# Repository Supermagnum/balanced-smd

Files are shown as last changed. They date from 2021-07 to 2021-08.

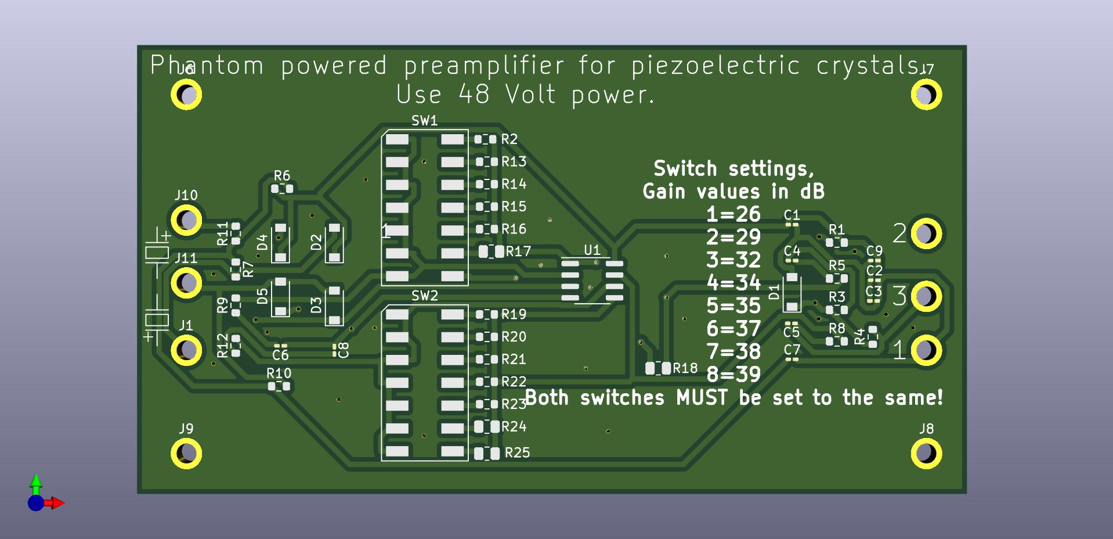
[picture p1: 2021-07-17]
front.jpg

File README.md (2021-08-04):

# balanced-smd
A small PCB that uses two LT6234CS8#TRPBF  op amps to amplify a signal from a contact microphone.

It has balanced output,input and should run on +48 phantom power. Shielded cable must with 3 leads be used for connection to the piezo crystals. Please use 0,5 W metal film resistors with 1% tolerance or better and audio quality capacitors.
C0G (NP0) or X7R capacitors is very good.

It is important that the circuit board is mounted inside a metal box, and Ø2mm conducting metal standoffs are used. The corner pads of the PCB board is reserved for that. Of course the PCB board and components must not come in contact with any metal surface expect the standoffs.

The circuit may benefit from a Zobel network, that is a 680 pF capacitor and a 150 ohms resistor in series between pin 2 and 3 on the output or the input connector. It should avoid high frequency oscillation in the cable.

Schematic diagram:
https://github.com/Supermagnum/balanced-smd/blob/main/smd-balanced.pdf

Component side picture with switch settings versus gain in dB:
https://github.com/Supermagnum/balanced-smd/blob/main/front.jpg

Back side:
https://github.com/Supermagnum/balanced-smd/blob/main/back.jpg

Aisler link:
https://aisler.net/p/YIWINLSK
Aisler can suply this assembled with the SMD components in place.

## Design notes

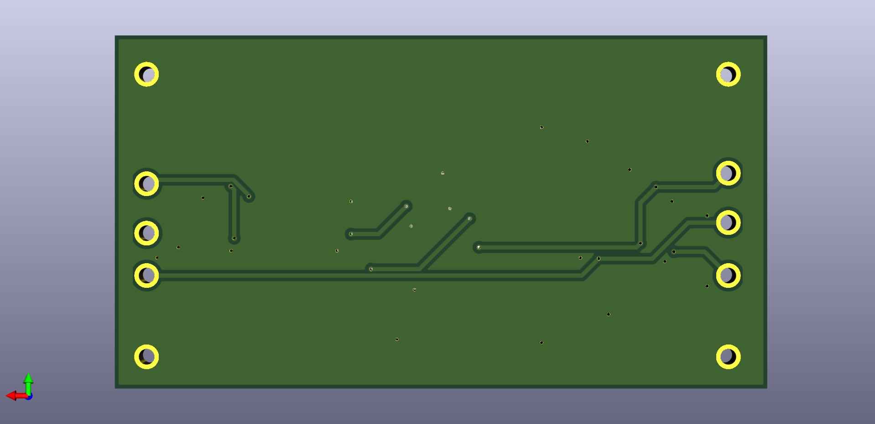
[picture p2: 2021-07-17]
back.jpg

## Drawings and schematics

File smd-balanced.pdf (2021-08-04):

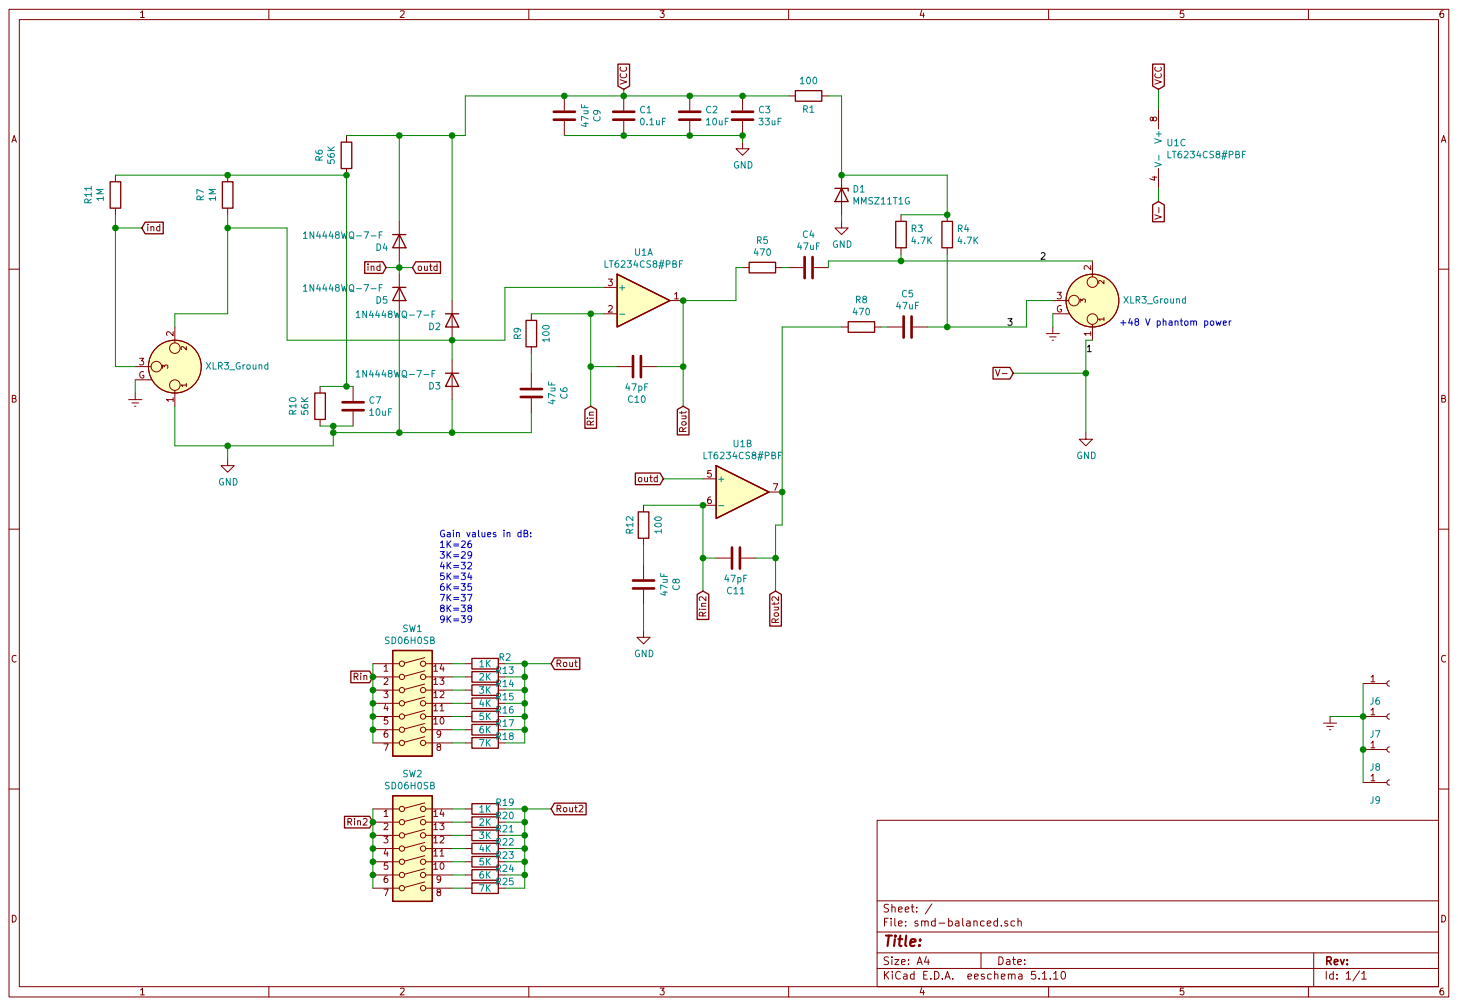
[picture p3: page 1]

Id: 1/1 Title: File: smd-balanced.sch Sheet: / C9 47uF D4

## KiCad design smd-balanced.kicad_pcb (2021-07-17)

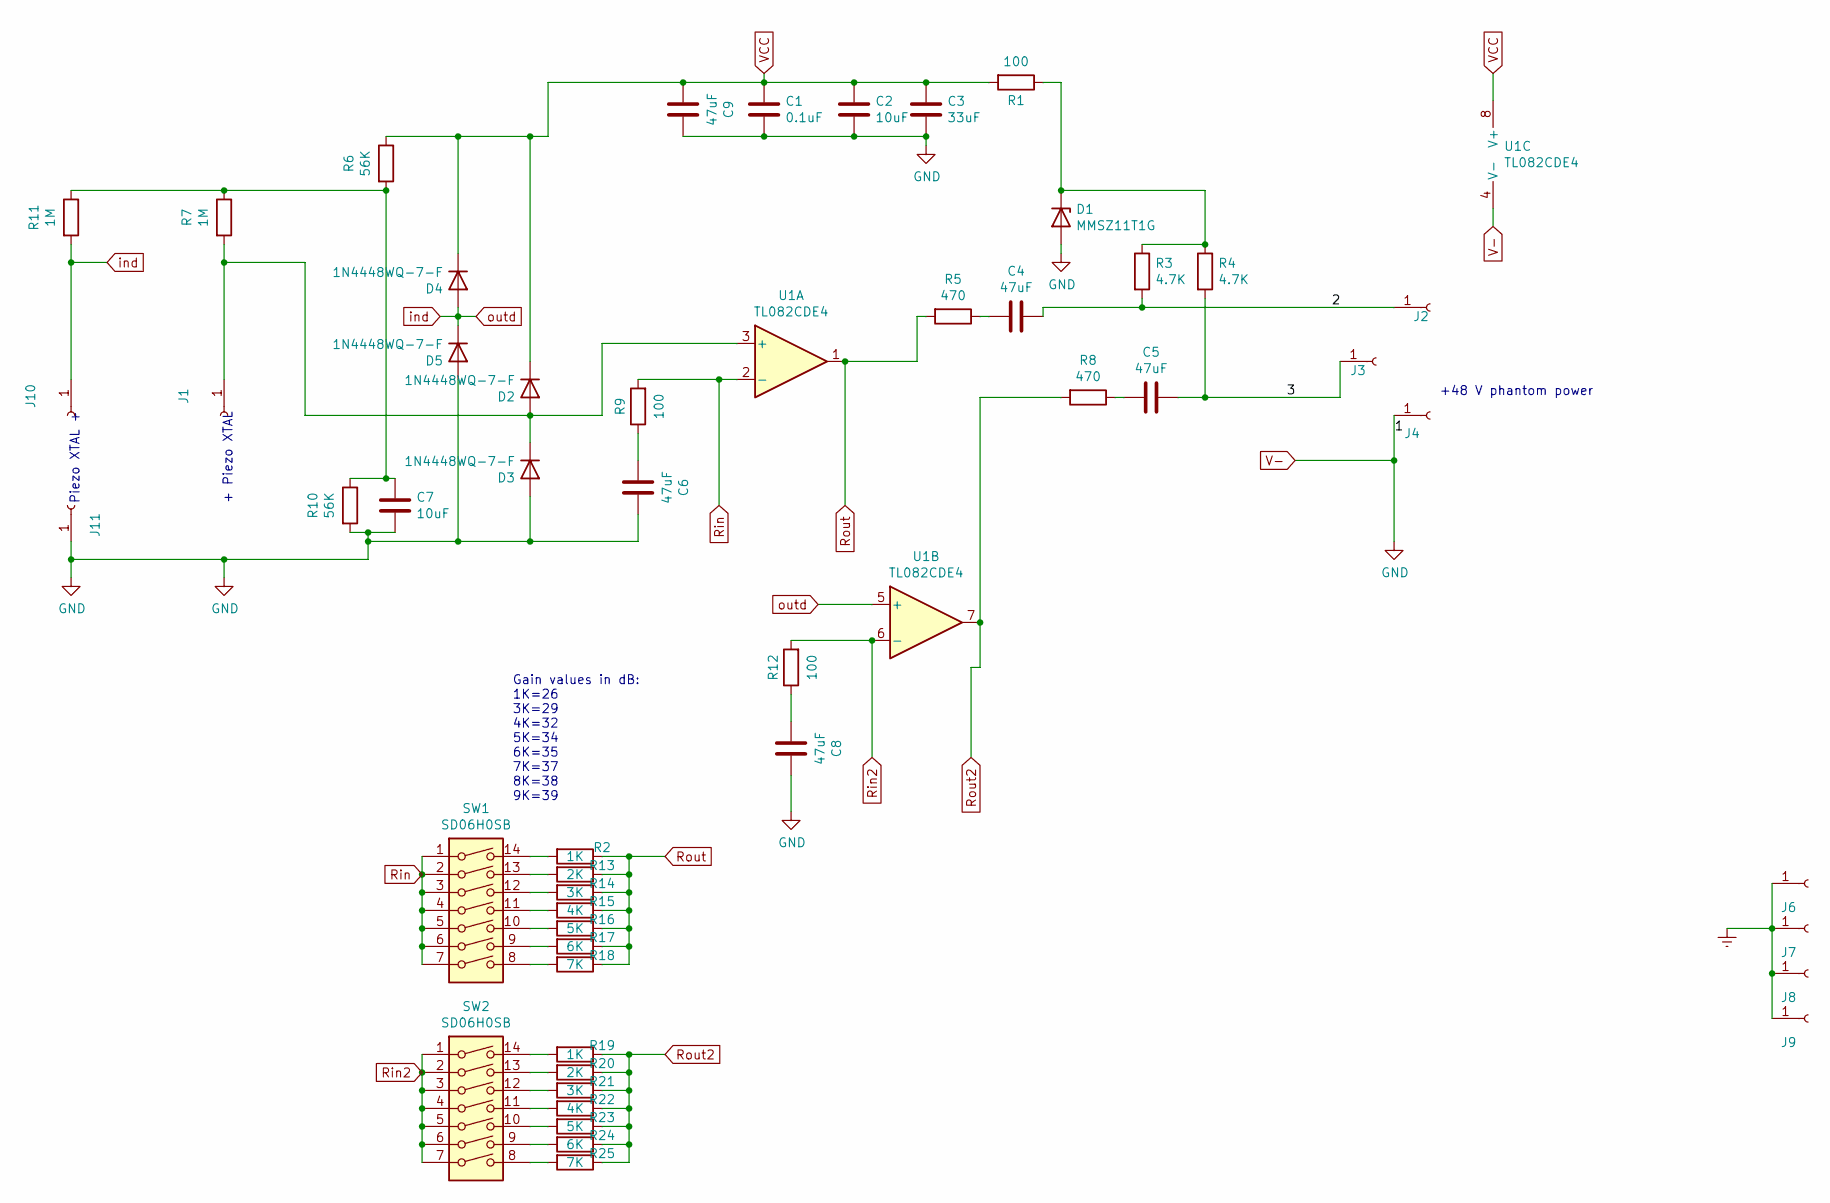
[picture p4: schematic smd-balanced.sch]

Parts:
C1: 0.1uF; C_0201_0603Metric_Pad0.64x0.40mm_HandSolder
C2, C7: 10uF; C_0201_0603Metric_Pad0.64x0.40mm_HandSolder
C3: 33uF; C_0201_0603Metric_Pad0.64x0.40mm_HandSolder
C4, C5, C6, C8, C9: 47uF; C_0201_0603Metric_Pad0.64x0.40mm_HandSolder
D1: MMSZ11T1G; D_SOD-123
D2, D3, D4, D5: 1N4448WQ-7-F; D_SOD-123
J1, J2, J3, J4, J6, J7, J8, J9, J10, J11: Conn_01x01_Female; MountingHole_2.2mm_M2_ISO7380_Pad
R1, R9, R12: 100; R_0603_1608Metric
R2, R19: 1K; R_0603_1608Metric
R3, R4: 4.7K; R_0603_1608Metric
R5, R8: 470; R_0603_1608Metric
R6, R10: 56K; R_0603_1608Metric
R7, R11: 1M; R_0603_1608Metric
R13, R20: 2K; R_0603_1608Metric
R14, R21: 3K; R_0603_1608Metric
R15, R22: 4K; R_0603_1608Metric
R16, R23: 5K; R_0603_1608Metric
R17, R24: 6K; R_0805_2012Metric
R18, R25: 7K; R_0805_2012Metric
SW1, SW2: SD06H0SB; SD07H1SB
U1: TL082CDE4; SOIC-8_3.9x4.9mm_P1.27mm

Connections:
/2: C4.1, J2.1, R3.2
/3: C5.1, J3.1, R4.2
Earth: J6.1, J7.1, J8.1, J9.1
unnamed: C4.2, R5.1
unnamed: C5.2, R8.1
unnamed: C6.2, R9.1
unnamed: C7.1, R6.2, R7.1, R10.1, R11.1
unnamed: C8.2, R12.1
unnamed: D1.1 (K), R1.1, R3.1, R4.1
unnamed: D2.2 (A), D3.1 (K), J1.1, R7.2, U1.3 (+)
unnamed: R2.2, SW1.14
unnamed: R13.2, SW1.13
unnamed: R14.2, SW1.12
unnamed: R15.2, SW1.11
unnamed: R16.2, SW1.10
unnamed: R17.2, SW1.9
unnamed: R18.2, SW1.8
unnamed: R19.2, SW2.14
unnamed: R20.2, SW2.13
unnamed: R21.2, SW2.12
unnamed: R22.2, SW2.11
unnamed: R23.2, SW2.10
unnamed: R24.2, SW2.9
unnamed: R25.2, SW2.8
Rin: R9.2, SW1.1, SW1.2, SW1.3, SW1.4, SW1.5, SW1.6, SW1.7, U1.2 (-)
Rin2: R12.2, SW2.1, SW2.2, SW2.3, SW2.4, SW2.5, SW2.6, SW2.7, U1.6 (-)
Rout: R2.1, R5.2, R13.1, R14.1, R15.1, R16.1, R17.1, R18.1, U1.1
Rout2: R8.2, R19.1, R20.1, R21.1, R22.1, R23.1, R24.1, R25.1, U1.7
V-: C1.2, C2.2, C3.2, C6.1, C7.2, C8.1, C9.1, D1.2 (A), D3.2 (A), D5.2 (A), J4.1, J11.1, R10.2, U1.4 (V-)
VCC: C1.1, C2.1, C3.1, C9.2, D2.1 (K), D4.1 (K), R1.2, R6.1, U1.8 (V+)
ind: D4.2 (A), D5.1 (K), J10.1, R11.2, U1.5 (+)

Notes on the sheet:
+48 V phantom power
Gain values in dB: 1K=26 3K=29 4K=32 5K=34 6K=35 7K=37 8K=38 9K=39
+ Piezo XTAL
Piezo XTAL +

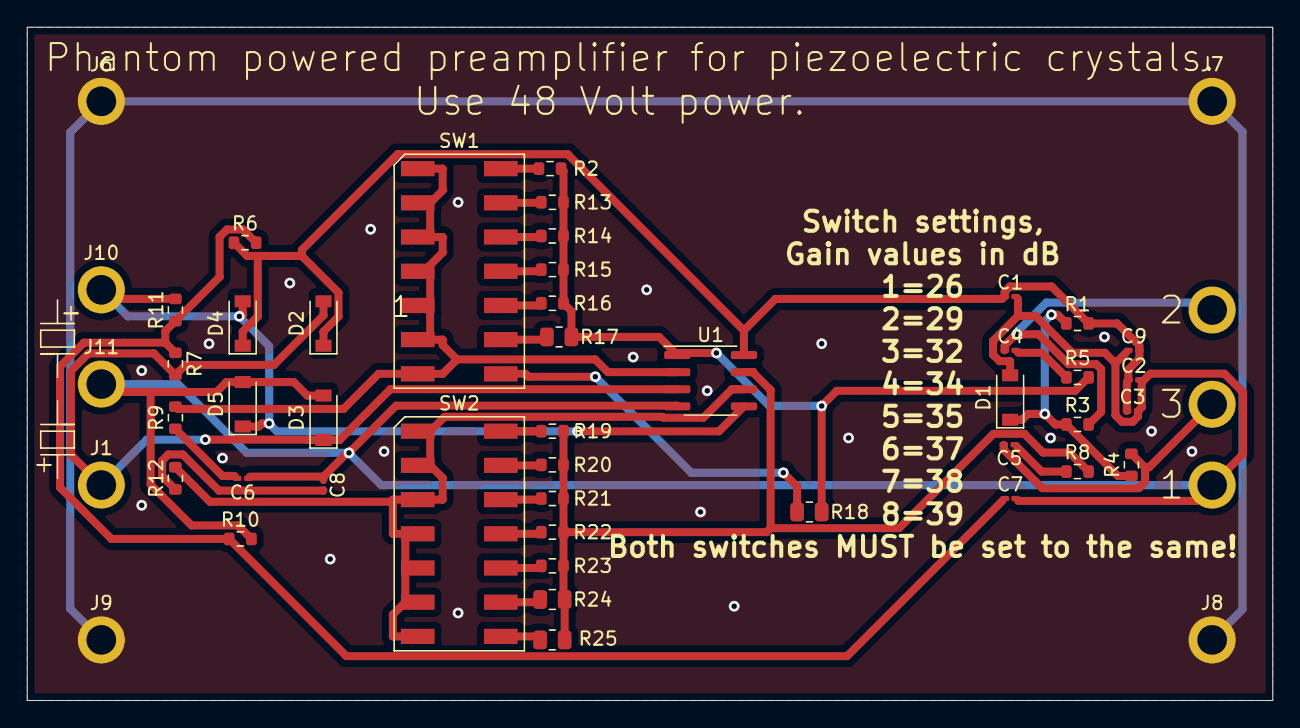
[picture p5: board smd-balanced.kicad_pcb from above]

Board: 2 copper layers, 92.5 x 50.0 mm, 52 parts (0 on the bottom side), 31 nets.
